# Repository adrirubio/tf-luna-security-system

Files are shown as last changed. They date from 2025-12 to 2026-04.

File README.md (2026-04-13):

# TF-Luna Security System
**Full Design Process**: [Blueprint Project](https://blueprint.hackclub.com/projects/7234)

An evolution of my Arduino-based security system that uses a TF-Luna LiDAR sensor to detect when someone passes through a bedroom door, triggering the ESP32-CAM to capture a photo of the intruder.

The system is built around a Freenove ESP32-S3-WROOM-1, which communicates with the TF-Luna over I2C to establish a baseline distance and detect motion. When an intruder is detected, the onboard camera captures an image and sends it to Home Assistant via Wi-Fi. A green LED indicates power status while a red LED flashes to signal an intruder alert. The entire system runs off a power bank and is housed in a custom 3D-printed case mounted with a custom carrier PCB, making it a compact, self-contained DIY security setup with future plans for AI-based person identification.

## Features

- **Intruder Detection:** Real-time motion detection using a TF-Luna LiDAR sensor with a focused 2-degree beam
- **Automatic Photo Capture:** ESP32-CAM captures an image when an intruder is detected passing through the door
- **Home Assistant Integration:** Sends captured images and alerts directly to Home Assistant over Wi-Fi
- **LED Indicators:** Green LED for power status, red LED flashes on intruder detection
- **I2C Communication:** Reliable sensor communication at 100Hz with the TF-Luna
- **Custom PCB:** Single carrier board designed in KiCad and manufactured by JLCPCB
- **Custom 3D Printed Case:** Designed in FreeCAD with mounting pillars and cutouts for all components
- **Power Bank Powered:** Runs off a standard power bank for easy and flexible placement
- **Autonomous Operation:** Runs continuously without manual interaction
- **Future AI Integration:** Planned AI-based identification to recognize the homeowner

## Hardware/BOM

| Component | Qty | Type |
|---|-----|---|
| Freenove ESP32-S3-WROOM-1 | 1 | Controller |
| TF-Luna LiDAR Sensor | 1 | LiDAR Sensor |
| microSD Card (32GB) | 1 | Storage |
| Custom Carrier PCB | 1 | PCB |
| Custom 3D Printed Case | 1 | Enclosure |
| Power Bank | 1 | Power |
| USB-A to USB-C Cable | 1 | Cable |
| Mounting Hardware (Assorted Screws) | 1 | Hardware |

## CAD Screenshots

| CAD Assembly (Front View)| CAD Assembly (Top View) |
|---|---|
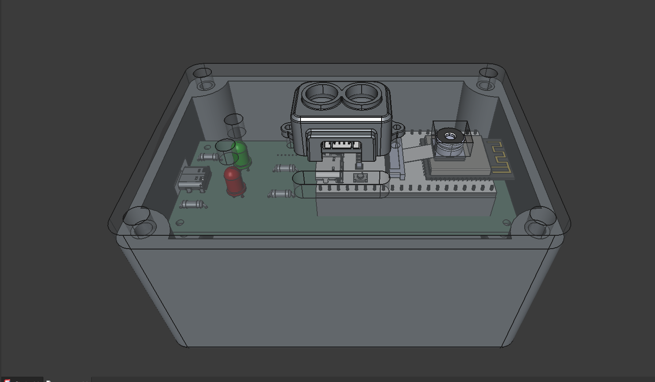
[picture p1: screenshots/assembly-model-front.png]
Assembly Model Front
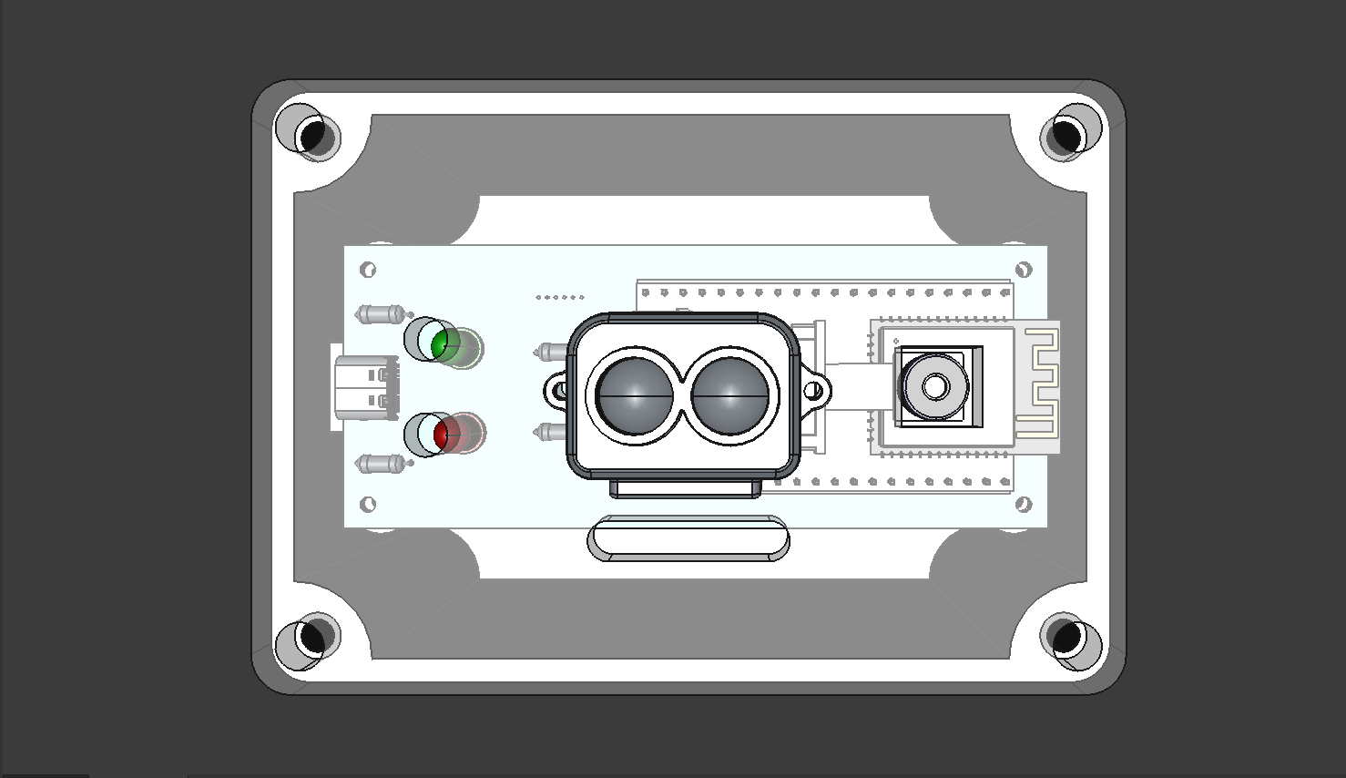
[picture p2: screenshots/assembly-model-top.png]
Assembly Model Top
|  |  |

| 3D Case (Front View) | 3D Case (Side View) |
|---|---|
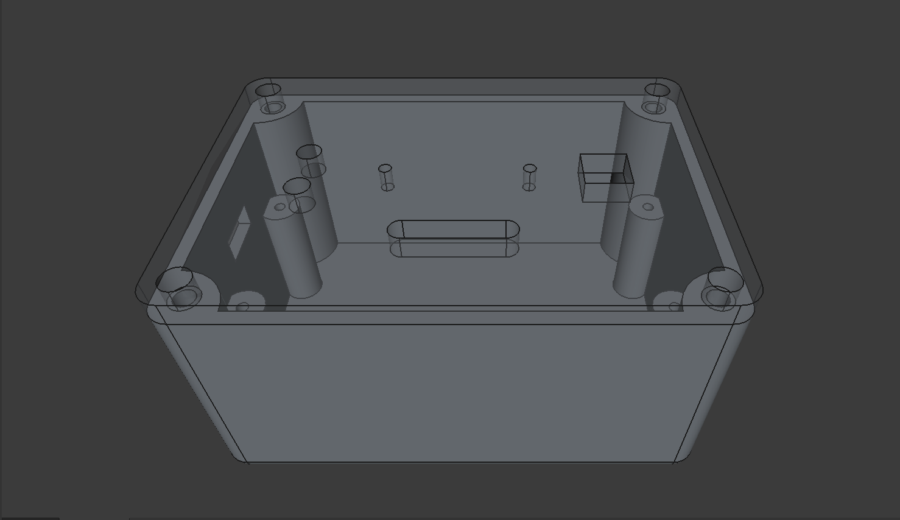
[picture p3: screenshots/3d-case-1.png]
3D Case Front
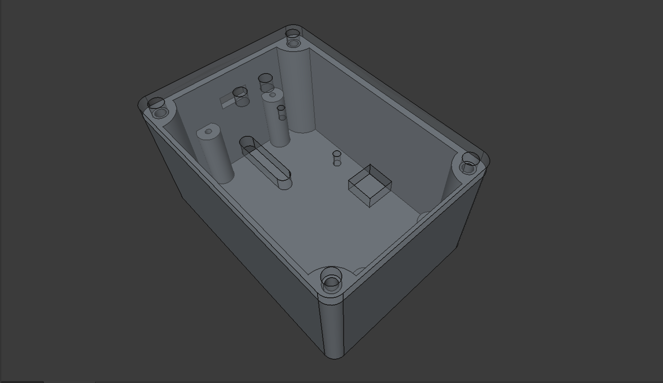
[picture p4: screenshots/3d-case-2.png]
3D Case Side
|  |  |

## PCB Screenshots

| PCB Layout |
|-------------------------------|
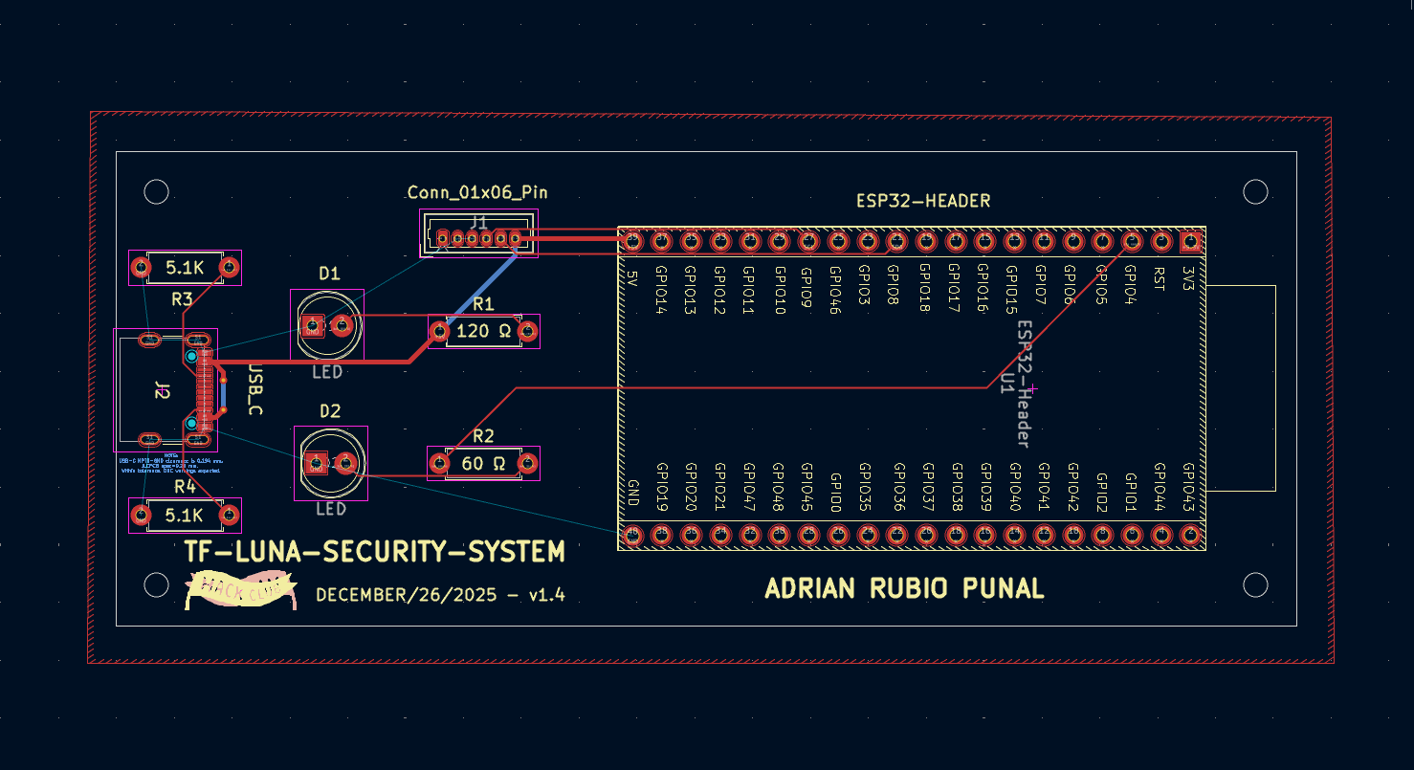
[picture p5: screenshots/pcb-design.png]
PCB Layout
|  |

| PCB 3D View (Front) | PCB 3D View (Back) |
|---|---|
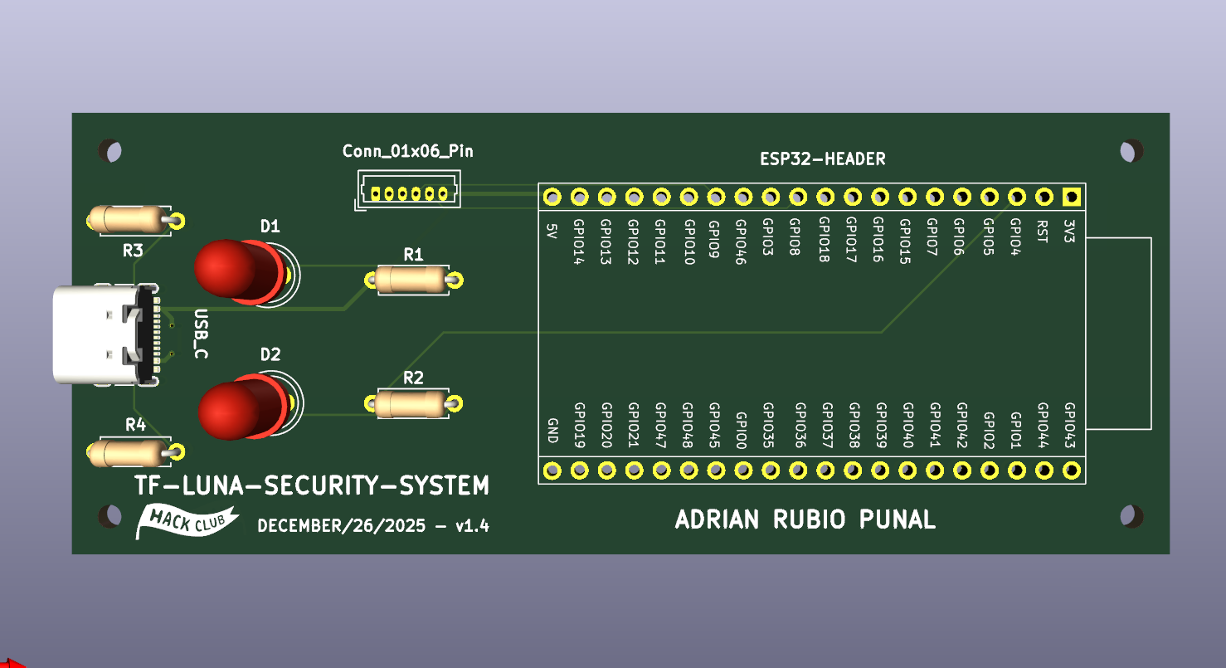
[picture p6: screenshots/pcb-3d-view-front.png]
PCB 3D View (Front)
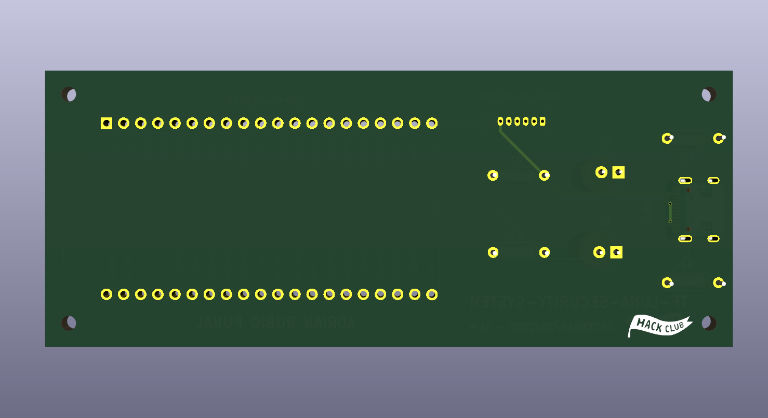
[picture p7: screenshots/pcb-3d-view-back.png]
PCB 3D View (Back)
|  |  |

## Usage
Mount the system above your bedroom door using the 3D-printed case. The TF-Luna LiDAR sensor establishes a baseline distance to the floor and continuously monitors for changes. When someone passes through the doorway, the sensor detects the distance change and triggers the ESP32-CAM to capture a photo. The image is then sent to Home Assistant over Wi-Fi, and the red LED flashes to indicate an intruder was detected. The green LED stays on to confirm the system is powered and running.

## TF-Luna Security System In Action

| Complete Assembly (Side View)|
|------------------------------|
| Complete Assembly Side |

| Complete Assembly (PCB and Case View) | Complete Assembly (Back View) |
|---|---|
| Complete Assembly PCB and Case | Complete Assembly Back |

### Security System Demo
<a href="https://github.com/adrirubio/tf-luna-security-system/raw/main/demo/video/security-system-demo.mp4">Click here to download the security system demo video (MP4)</a>

### YouTube Demo
[Watch the demo on YouTube](https://youtu.be/43d7Ib5dUhA)

## License

MIT License

---

> GitHub [@adrirubio](https://github.com/adrirubio) &nbsp;&middot;&nbsp;

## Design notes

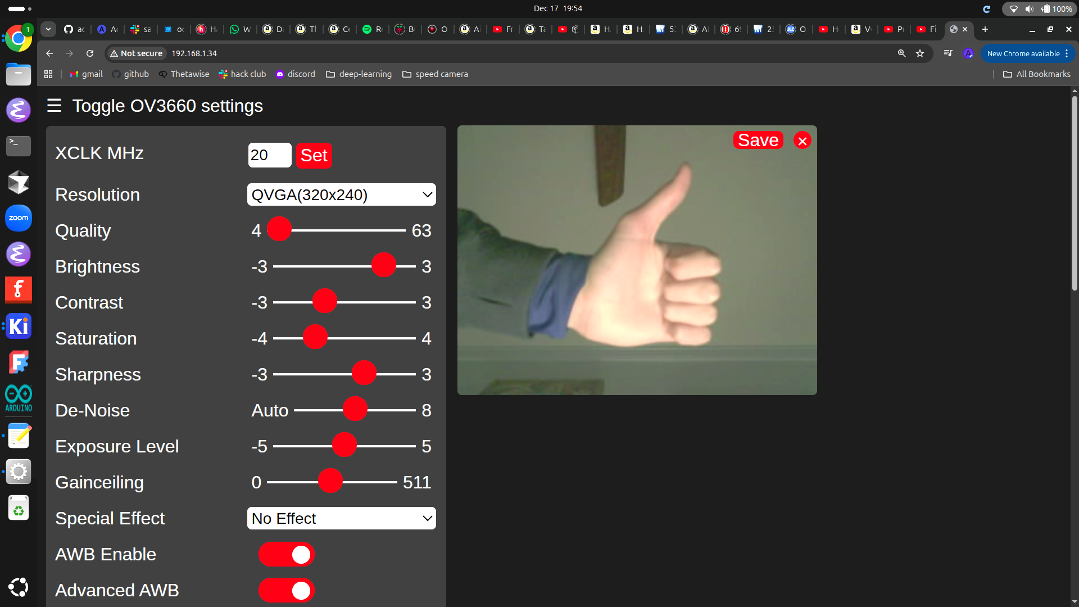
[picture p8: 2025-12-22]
demo/ESP32-S3-WebServer-picture/webserver-thumbs-up.png

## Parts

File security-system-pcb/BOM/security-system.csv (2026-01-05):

Comment | Designator | Footprint | LCSC Part Number
USB Type-C Receptacle, USB 2.0, Right-Angle, Top-Mount, SMT, TH Shell Stakes, 5A 48V | J2 | USB_C_Receptacle_GCT_USB4105-xx-A_16P_TopMnt_Horizontal | C3020560

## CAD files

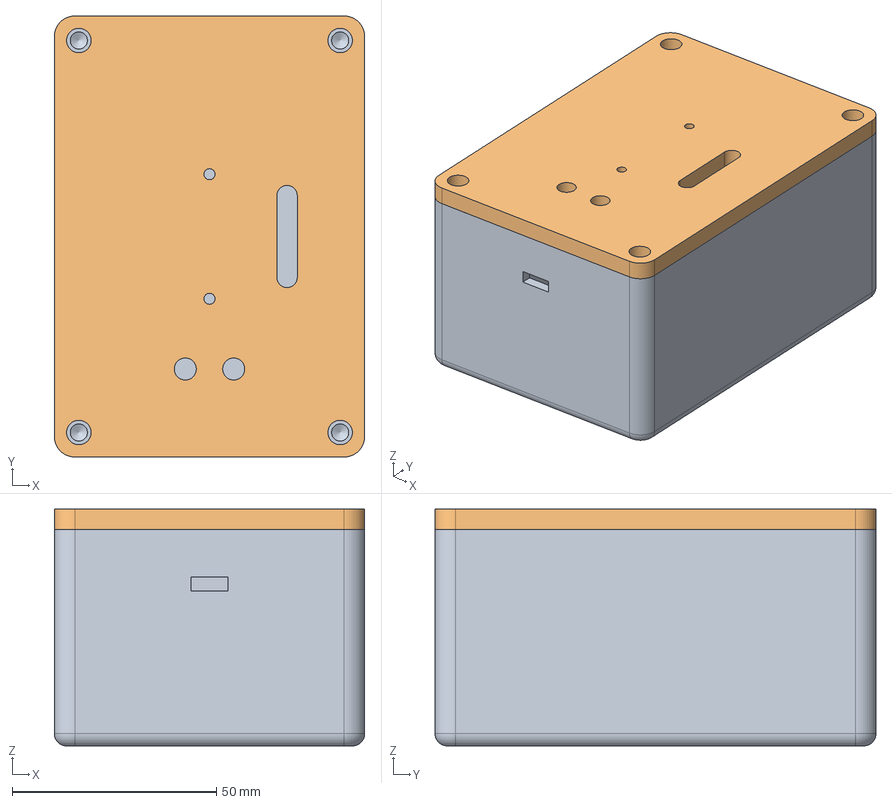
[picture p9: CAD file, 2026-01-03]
security-system-case/Case.FCStd
76.0 x 108.0 x 58.0 mm
case-base
case-cover

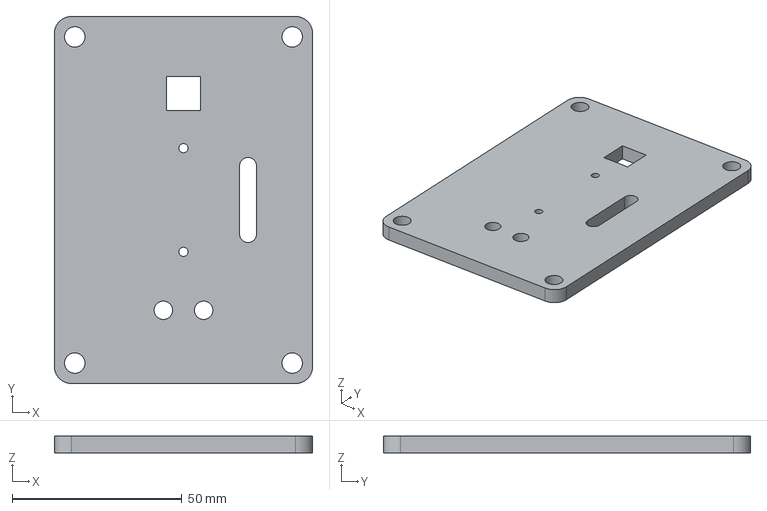
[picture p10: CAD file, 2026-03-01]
security-system-case/STEP-files/case-cover.step
76.0 x 108.0 x 5.00 mm

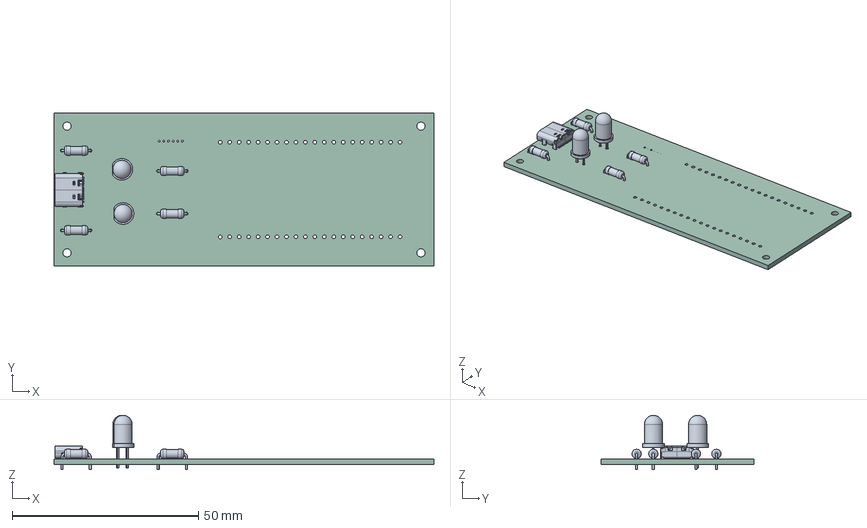
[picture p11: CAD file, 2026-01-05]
security-system-pcb/security-system-pcb/security-system.step
102.0 x 41.0 x 14.6 mm
LED_D5.0mm x 2
R_Axial_DIN0207_L6.3mm_D2.5mm_P7.62mm_Horizontal x 4
USB_C_Receptacle_GCT_USB4105-xx-A_16P_TopMnt_Horizontal
security-system_PCB

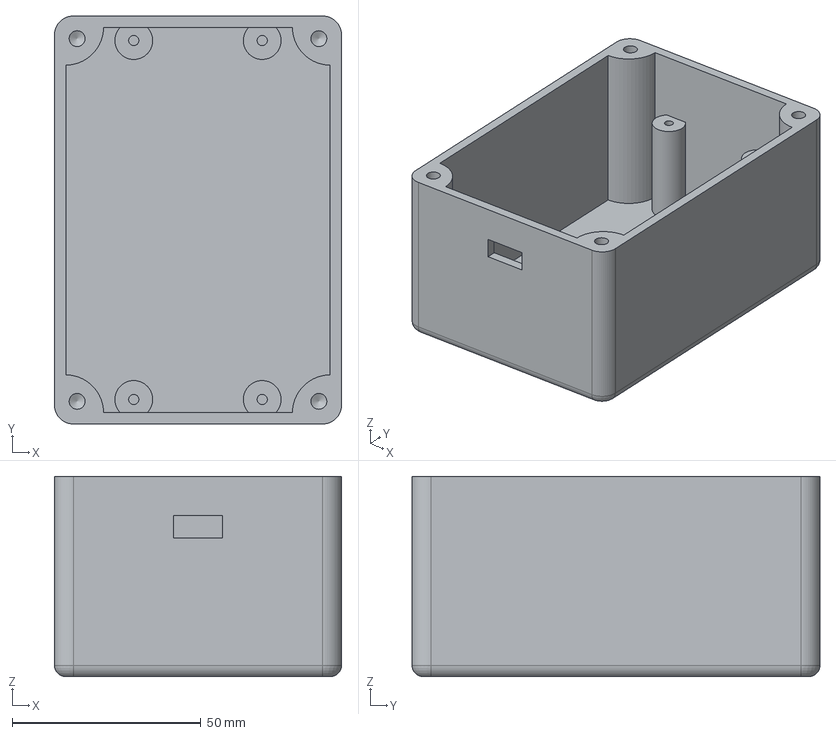
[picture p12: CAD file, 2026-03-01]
security-system-case/STEP-files/case-base.step
76.0 x 108.0 x 53.0 mm

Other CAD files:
security-system-case/STL-files/enclosure-cover.stl
security-system-case/STL-files/enclosure-base.stl

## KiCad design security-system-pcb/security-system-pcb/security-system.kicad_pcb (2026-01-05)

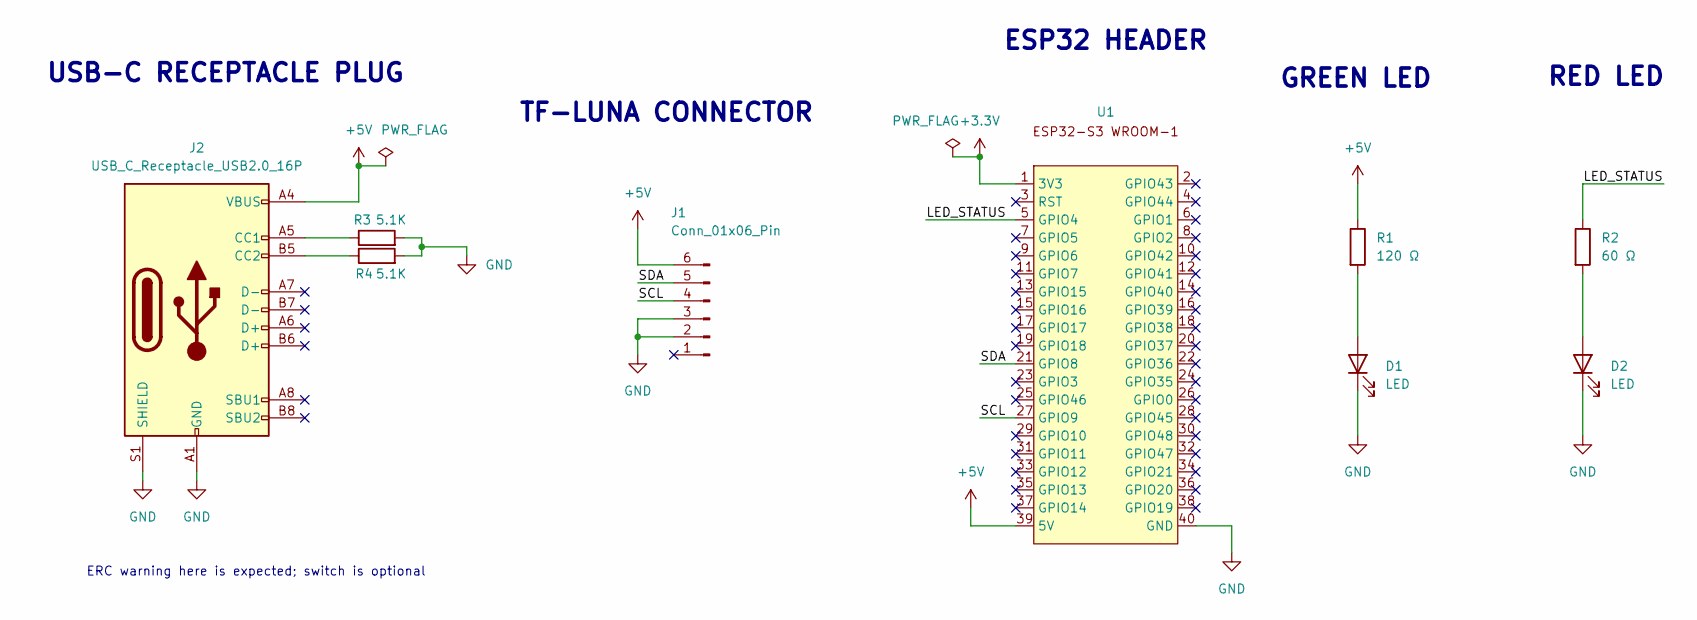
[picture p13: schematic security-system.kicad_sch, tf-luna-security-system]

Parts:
D1, D2: LED; LED_D5.0mm
J1: Conn_01x06_Pin; Molex_PicoBlade_53047-0610_1x06_P1.25mm_Vertical
J2: USB_C_Receptacle_USB2.0_16P; USB_C_Receptacle_GCT_USB4105-xx-A_16P_TopMnt_Horizontal
R1: 120 Ω; R_Axial_DIN0207_L6.3mm_D2.5mm_P7.62mm_Horizontal
R2: 60 Ω; R_Axial_DIN0207_L6.3mm_D2.5mm_P7.62mm_Horizontal
R3, R4: 5.1K; R_Axial_DIN0207_L6.3mm_D2.5mm_P7.62mm_Horizontal
U1: ESP32-Header; esp32-header

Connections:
+3.3V: U1.1 (3V3)
+5V: J1.6, J2.A4 (VBUS), J2.A9 (VBUS), J2.B4 (VBUS), J2.B9 (VBUS), R1.1, U1.39 (5V)
/LED_STATUS: R2.1, U1.5 (GPIO4)
/SCL: J1.4, U1.27 (GPIO9)
/SDA: J1.5, U1.21 (GPIO8)
GND: D1.1 (K), D2.1 (K), J1.2, J1.3, J2.A1 (GND), J2.A12 (GND), J2.B1 (GND), J2.B12 (GND), J2.S1 (SHIELD), R3.2, R4.2, U1.40 (GND)
unnamed: D1.2 (A), R1.2
unnamed: D2.2 (A), R2.2
unnamed: J2.A5 (CC1), R3.1
unnamed: J2.B5 (CC2), R4.1

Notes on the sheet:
TF-LUNA CONNECTOR
RED LED
USB-C RECEPTACLE PLUG
ERC warning here is expected; switch is optional
GREEN LED
ESP32 HEADER

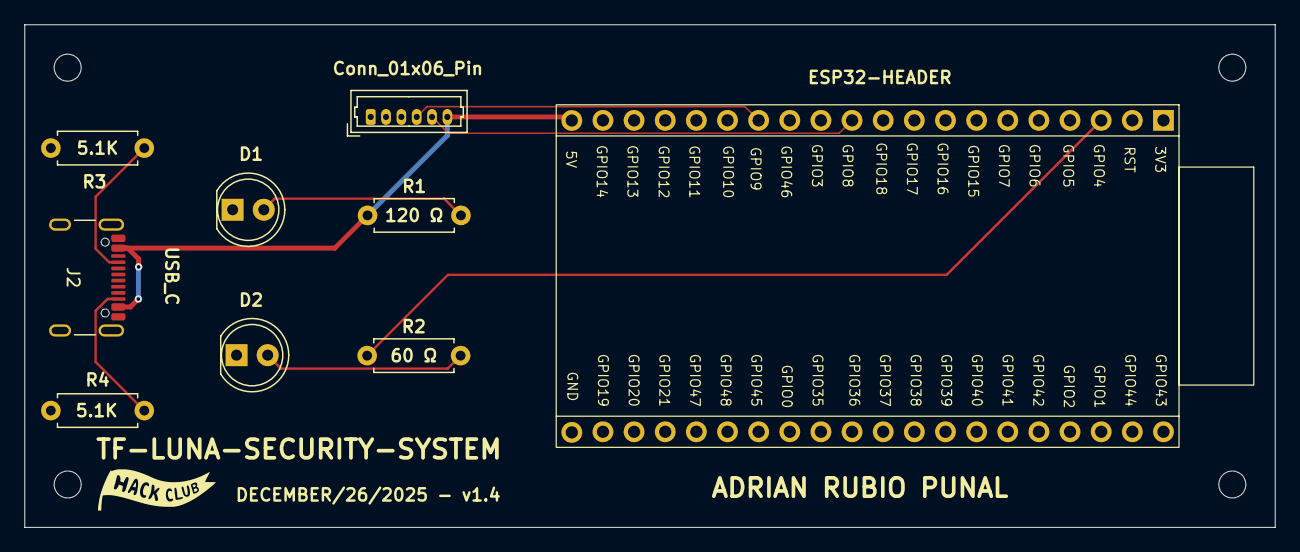
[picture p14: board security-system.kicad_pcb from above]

Board: 2 copper layers, 102.0 x 41.0 mm, 9 parts (0 on the bottom side), 9 nets.

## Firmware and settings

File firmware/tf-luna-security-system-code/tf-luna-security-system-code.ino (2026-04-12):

// ============================================================================
//  Security System — TF-Luna + ESP32-S3 Camera
// ----------------------------------------------------------------------------
//  IMPORTANT: In Arduino IDE select a partition scheme with at least ~2 MB of
//  LittleFS/SPIFFS space (e.g. "8M with spiffs (3MB APP/1.5MB SPIFFS)" or
//  larger). LittleFS reuses the SPIFFS partition. Without enough space the
//  circular photo buffer will drop captures.
// ============================================================================

#include <Wire.h>
#include <WiFi.h>
#include <WebServer.h>
#include <ESPmDNS.h>
#include <TFLI2C.h>
#include <LittleFS.h>
#include <time.h>
#include "esp_camera.h"

// mDNS hostname: http://security-system.local/
#define MDNS_HOSTNAME "security-system"

#include "board_config.h"

// ---- Wi-Fi Station settings ----
const char *WIFI_SSID = "MOVISTAR-WIFI6-B410";
const char *WIFI_PASS = "LE2xPxeBy7jPvEKYT6Qw";

// ---- TF-Luna I2C ----
TFLI2C tflI2C;
uint8_t tflunaAddr = 0x10;

// ---- Detection settings ----
#define WARMUP_MS           5000     // wait 5s before touching the sensor
#define BASELINE_MS         10000    // sample baseline for 10s
#define BASELINE_INTERVAL   100      // ms between baseline samples
#define TRIGGER_THRESHOLD   20       // cm — clearly something in the way
#define COOLDOWN_MS         250      // ms lockout after a capture (fast burst)
#define POLL_INTERVAL_MS    100      // monitoring sample interval
#define MAX_VALID_DIST      800      // TF-Luna max range cm

// ---- Sensor health ----
#define BAD_READ_LIMIT      8        // consecutive bad reads → degraded mode
#define RESET_RECOVER_MS    1500     // time to allow after a quick reset

// ---- Photo storage ----
#define MAX_PHOTOS          100
#define META_PATH           "/meta.bin"

// ---- System state ----
enum SystemState { STATE_WARMUP, STATE_CALIBRATING, STATE_MONITORING, STATE_TRIGGERED, STATE_COOLDOWN };
volatile SystemState systemState = STATE_WARMUP;

int  baselineDistance  = 0;
int  lastDistance      = -1;
int  lastBreakDistance = 0;
unsigned long lastBreakEpoch = 0;

unsigned long stateStart    = 0;
unsigned long cooldownStart = 0;
unsigned long bootMillis    = 0;

long calibSum   = 0;
int  calibCount = 0;

// ---- Sensor health tracking ----
int  badReadStreak   = 0;
bool degraded        = false;
int  totalQuickResets = 0;

// ---- Persistent metadata (saved to LittleFS) ----
struct __attribute__((packed)) Meta {
  uint32_t magic;                  // 0x5345434B "SECK"
  uint32_t nextIndex;              // next slot to write (0..MAX_PHOTOS-1)
  uint32_t totalCaptures;          // lifetime counter
  uint32_t epoch[MAX_PHOTOS];      // unix epoch for each slot (0 if empty)
  int16_t  distance[MAX_PHOTOS];   // distance at trigger
  int16_t  baseline[MAX_PHOTOS];   // baseline at trigger
};
Meta meta;

// ---- Web server ----
WebServer server(80);

// ======================= I2C =======================

void startI2C() {
  pinMode(8, INPUT_PULLUP);
  pinMode(9, INPUT_PULLUP);
  Wire.begin(8, 9);
  Wire.setClock(100000);
}

void stopI2C() {
  Wire.end();
}

// ======================= TF-Luna =======================

// Aggressive boot-time recovery: scan the bus, hard-reset whatever
// looks like a TF-Luna at any address, and wait for it to come back
// at the default 0x10. Survives a sensor whose EEPROM got corrupted
// into a non-default I2C address.
void tflunaForceFactoryReset() {
  Serial.println("TF-Luna: forcing factory reset...");

  for (int attempt = 1; attempt <= 3; attempt++) {
    Serial.printf("  Attempt %d/3\n", attempt);

    // 1. Scan bus
    uint8_t found[8];
    int nFound = 0;
    for (uint8_t a = 0x08; a <= 0x77 && nFound < 8; a++) {
      Wire.beginTransmission(a);
      if (Wire.endTransmission() == 0) {
        Serial.printf("    bus device @ 0x%02X\n", a);
        found[nFound++] = a;
      }
    }
    if (nFound == 0) {
      Serial.println("    no I2C devices on bus — check wiring/power");
      delay(500);
      continue;
    }

    // 2. Hard-reset every responding address (TF-Luna ignores reset
    //    sent to wrong address — safe to spray)
    for (int i = 0; i < nFound; i++) {
      Serial.printf("    Hard_Reset(0x%02X)\n", found[i]);
      tflI2C.Hard_Reset(found[i]);
      delay(200);
    }

    // 3. Wait for sensor to reboot
    Serial.println("    waiting 4s for reboot...");
    delay(4000);

    // 4. Bounce the bus so the controller forgets any stuck state
    stopI2C();
    delay(100);
    startI2C();
    delay(300);

    // 5. Verify default address is alive
    Wire.beginTransmission(tflunaAddr);
    if (Wire.endTransmission() == 0) {
      Serial.printf("    TF-Luna present @ 0x%02X — restoring defaults\n", tflunaAddr);
      tflI2C.Soft_Reset(tflunaAddr);    delay(800);
      tflI2C.Set_Enable(tflunaAddr);    delay(50);
      tflI2C.Set_Cont_Mode(tflunaAddr); delay(50);
      uint16_t fps = 10;               // 10Hz — match our poll rate, save power
      tflI2C.Set_Frame_Rate(fps, tflunaAddr); delay(50);
      // NOT calling Save_Settings — protect EEPROM from wear
      Serial.println("TF-Luna: factory reset complete");
      return;
    }
    Serial.println("    sensor not at 0x10 yet, retrying...");
  }
  Serial.println("TF-Luna: factory reset gave up — continuing anyway");
}

// Quick reset: bounce I2C bus + soft-reset sensor. Same effect as
// unplug/replug but without touching the cable. Takes ~1.5s.
void tflunaQuickReset() {
  Serial.println("TF-Luna: quick reset (I2C bounce + soft reset)...");
  totalQuickResets++;
  stopI2C();
  delay(100);
  startI2C();
  delay(200);
  tflI2C.Soft_Reset(tflunaAddr);
  delay(800);
  tflI2C.Set_Enable(tflunaAddr);
  delay(50);
  tflI2C.Set_Cont_Mode(tflunaAddr);
  delay(50);
  uint16_t fps = 10;                  // 10Hz — match poll rate, save power
  tflI2C.Set_Frame_Rate(fps, tflunaAddr);
  delay(50);
  badReadStreak = 0;
  Serial.println("TF-Luna: quick reset done");
}

int tflunaReadDistance() {
  int16_t dist = 0, flux = 0, temp = 0;
  bool ok = tflI2C.getData(dist, flux, temp, tflunaAddr);

  if (ok && dist > 0 && dist <= MAX_VALID_DIST && flux > 20) {
    // Good read — healthy signal
    if (badReadStreak > 0) badReadStreak--;
    if (badReadStreak == 0 && degraded) {
      degraded = false;
      Serial.println("Sensor: readings recovered");
    }
    return dist;
  }

  // Log what the sensor actually returned so we can diagnose
  if (ok) {
    Serial.printf("Sensor: suspect read dist=%d flux=%d temp=%d\n",
                  dist, flux, temp);
  }

  badReadStreak++;
  if (badReadStreak >= BAD_READ_LIMIT && !degraded) {
    degraded = true;
    Serial.printf("Sensor: DEGRADED (%d consecutive bad reads)\n", badReadStreak);
    tflunaQuickReset();
  }
  return -1;
}

// ======================= Camera =========================

static bool startCamera() {
  camera_config_t config;
  config.ledc_channel = LEDC_CHANNEL_0;
  config.ledc_timer   = LEDC_TIMER_0;

  config.pin_d0 = Y2_GPIO_NUM;
  config.pin_d1 = Y3_GPIO_NUM;
  config.pin_d2 = Y4_GPIO_NUM;
  config.pin_d3 = Y5_GPIO_NUM;
  config.pin_d4 = Y6_GPIO_NUM;
  config.pin_d5 = Y7_GPIO_NUM;
  config.pin_d6 = Y8_GPIO_NUM;
  config.pin_d7 = Y9_GPIO_NUM;

  config.pin_xclk  = XCLK_GPIO_NUM;
  config.pin_pclk  = PCLK_GPIO_NUM;
  config.pin_vsync = VSYNC_GPIO_NUM;
  config.pin_href  = HREF_GPIO_NUM;

  config.pin_sccb_sda = SIOD_GPIO_NUM;
  config.pin_sccb_scl = SIOC_GPIO_NUM;

  config.pin_pwdn  = PWDN_GPIO_NUM;
  config.pin_reset = RESET_GPIO_NUM;

  config.xclk_freq_hz = 10000000;
  config.pixel_format = PIXFORMAT_JPEG;
  config.frame_size   = FRAMESIZE_VGA;
  config.jpeg_quality = 18;          // higher number = smaller file
  config.fb_count     = 1;
  config.grab_mode    = CAMERA_GRAB_WHEN_EMPTY;

  if (psramFound()) {
    config.fb_location = CAMERA_FB_IN_PSRAM;
  } else {
    config.fb_location = CAMERA_FB_IN_DRAM;
  }

  esp_err_t err = esp_camera_init(&config);
  if (err != ESP_OK) {
    Serial.printf("Camera init failed: 0x%x\n", err);
    return false;
  }
  return true;
}

static void stopCamera() {
  esp_camera_deinit();
}

// ======================= Storage ========================

String photoPath(uint32_t slot) {
  char buf[20];
  snprintf(buf, sizeof(buf), "/img_%03lu.jpg", (unsigned long)slot);
  return String(buf);
}

void saveMeta() {
  File f = LittleFS.open(META_PATH, "w");
  if (!f) {
    Serial.println("saveMeta: open failed");
    return;
  }
  f.write((const uint8_t *)&meta, sizeof(meta));
  f.close();
}

void loadMeta() {
  memset(&meta, 0, sizeof(meta));
  meta.magic = 0x5345434B;
  if (!LittleFS.exists(META_PATH)) {
    Serial.println("No meta file — starting fresh");
    return;
  }
  File f = LittleFS.open(META_PATH, "r");
  if (!f) return;
  if (f.size() != sizeof(Meta)) {
    Serial.println("meta.bin size mismatch — resetting");
    f.close();
    memset(&meta, 0, sizeof(meta));
    meta.magic = 0x5345434B;
    return;
  }
  f.read((uint8_t *)&meta, sizeof(meta));
  f.close();
  if (meta.magic != 0x5345434B) {
    Serial.println("meta.bin magic bad — resetting");
    memset(&meta, 0, sizeof(meta));
    meta.magic = 0x5345434B;
    return;
  }
  Serial.printf("Loaded meta: nextIndex=%u totalCaptures=%u\n",
                meta.nextIndex, meta.totalCaptures);
}

uint32_t storedPhotoCount() {
  return meta.totalCaptures < MAX_PHOTOS ? meta.totalCaptures : MAX_PHOTOS;
}

// Slot of newest photo (nth = 0 means newest)
int32_t nthNewestSlot(uint32_t n) {
  uint32_t count = storedPhotoCount();
  if (n >= count) return -1;
  // nextIndex points to where the NEXT photo will be written
  int32_t slot = ((int32_t)meta.nextIndex - 1 - (int32_t)n);
  slot %= MAX_PHOTOS;
  if (slot < 0) slot += MAX_PHOTOS;
  return slot;
}

// ======================= Capture ========================

bool capturePhoto(int distanceAtTrigger) {
  stopI2C();
  delay(10);

  if (!startCamera()) {
    Serial.println("Camera init failed");
    startI2C();
    return false;
  }

  camera_fb_t *fb = esp_camera_fb_get();
  if (!fb) {
    Serial.println("Capture failed");
    stopCamera();
    startI2C();
    return false;
  }

  uint32_t slot = meta.nextIndex % MAX_PHOTOS;
  String path = photoPath(slot);
  if (LittleFS.exists(path)) LittleFS.remove(path);

  bool ok = false;
  File f = LittleFS.open(path, "w");
  if (f) {
    size_t wrote = f.write(fb->buf, fb->len);
    f.close();
    ok = (wrote == fb->len);
    if (!ok) {
      Serial.println("Photo write incomplete");
      LittleFS.remove(path);
    }
  } else {
    Serial.println("Photo open for write failed");
  }

  Serial.printf("Photo %s (%u bytes) %s\n", path.c_str(),
                (unsigned)fb->len, ok ? "OK" : "FAIL");

  esp_camera_fb_return(fb);
  stopCamera();
  delay(10);
  startI2C();

  if (ok) {
    time_t now = time(nullptr);
    meta.epoch[slot]    = (now > 1700000000) ? (uint32_t)now : 0;
    meta.distance[slot] = (int16_t)distanceAtTrigger;
    meta.baseline[slot] = (int16_t)baselineDistance;
    meta.nextIndex      = (meta.nextIndex + 1) % MAX_PHOTOS;
    meta.totalCaptures++;
    saveMeta();
    lastBreakDistance = distanceAtTrigger;
    lastBreakEpoch    = (now > 1700000000) ? (uint32_t)now : 0;
  }
  return ok;
}

// ======================= Helpers =========================

String formatUptime(unsigned long ms) {
  unsigned long secs = ms / 1000;
  unsigned long mins = secs / 60;
  unsigned long hrs  = mins / 60;
  char buf[16];
  snprintf(buf, sizeof(buf), "%02lu:%02lu:%02lu",
           hrs, mins % 60, secs % 60);
  return String(buf);
}

String formatEpoch(uint32_t epoch) {
  if (epoch < 1700000000) return String("—");
  time_t t = epoch;
  struct tm tmv;
  localtime_r(&t, &tmv);
  char buf[24];
  snprintf(buf, sizeof(buf), "%04d-%02d-%02d %02d:%02d:%02d",
           tmv.tm_year + 1900, tmv.tm_mon + 1, tmv.tm_mday,
           tmv.tm_hour, tmv.tm_min, tmv.tm_sec);
  return String(buf);
}

const char *stateName(SystemState s) {
  switch (s) {
    case STATE_WARMUP:      return "WARMUP";
    case STATE_CALIBRATING: return "CALIBRATING";
    case STATE_MONITORING:  return "MONITORING";
    case STATE_TRIGGERED:   return "TRIGGERED";
    case STATE_COOLDOWN:    return "COOLDOWN";
  }
  return "UNKNOWN";
}

// ======================= Web: shared CSS ================

const char PAGE_CSS[] PROGMEM = R"CSS(
:root{
  --bg:#050505;--panel:#0b0b0b;--border:#1a1a1a;--border-hi:#262626;
  --fg:#c8c8c8;--dim:#555;--accent:#00ff66;--accent-dim:#00aa44;
  --warn:#ff3344;--info:#00d0ff;--amber:#ffb000;
}
*{box-sizing:border-box;margin:0;padding:0}
html,body{background:var(--bg);color:var(--fg);
  font-family:'JetBrains Mono','Fira Code',Menlo,Consolas,monospace;
  min-height:100vh}
body{padding:24px;max-width:1400px;margin:0 auto}
a{color:var(--accent);text-decoration:none}
header{display:flex;align-items:center;justify-content:space-between;
  padding-bottom:16px;border-bottom:1px solid var(--border);margin-bottom:24px}
header h1{font-size:1.3rem;letter-spacing:.2em;color:var(--accent);font-weight:400}
header h1::before{content:'> ';color:var(--accent-dim)}
.state{font-size:.7rem;letter-spacing:.2em;padding:5px 14px;
  border:1px solid var(--border-hi);text-transform:uppercase;color:var(--accent)}
.state.warmup,.state.calibrating{color:var(--info);border-color:var(--info)}
.state.monitoring{color:var(--accent);border-color:var(--accent-dim)}
.state.triggered{color:var(--warn);border-color:var(--warn)}
.state.cooldown{color:var(--amber);border-color:var(--amber)}
main{display:grid;grid-template-columns:minmax(280px,1fr) 2fr;gap:20px}
@media(max-width:760px){main{grid-template-columns:1fr}}
.panel{background:var(--panel);border:1px solid var(--border);padding:18px}
.panel h2{font-size:.65rem;letter-spacing:.25em;color:var(--accent-dim);
  text-transform:uppercase;margin-bottom:14px;font-weight:400}
.panel h2::before{content:'// '}
.row{display:flex;justify-content:space-between;align-items:baseline;
  padding:7px 0;border-bottom:1px dashed #141414;font-size:.82rem}
.row:last-child{border:0}
.label{color:var(--dim)}
.val{color:var(--accent)}
.val.warn{color:var(--warn)}
.val.dim{color:var(--dim)}
.image-wrap{display:flex;align-items:center;justify-content:center;
  min-height:320px;background:#000;border:1px solid var(--border)}
.image-wrap img{width:100%;height:auto;display:block;filter:contrast(1.05) saturate(.95)}
.image-empty{color:var(--dim);font-size:.8rem;letter-spacing:.15em;padding:60px 0}
.caption{font-size:.7rem;color:var(--dim);padding:10px 2px 0;
  display:flex;justify-content:space-between}
.caption .val{color:var(--accent-dim)}
.actions{margin-top:24px;display:flex;gap:12px;flex-wrap:wrap}
.btn{display:inline-block;padding:10px 20px;background:transparent;
  color:var(--accent);border:1px solid var(--accent-dim);font-family:inherit;
  font-size:.75rem;letter-spacing:.18em;text-transform:uppercase;cursor:pointer;
  transition:.15s}
.btn:hover{background:var(--accent);color:var(--bg)}
.btn.ghost{color:var(--dim);border-color:var(--border-hi)}
.btn.ghost:hover{background:var(--border-hi);color:var(--fg)}
footer{margin-top:32px;padding-top:12px;border-top:1px solid var(--border);
  font-size:.65rem;color:var(--dim);letter-spacing:.15em;text-align:center}
footer::before{content:'[ '}footer::after{content:' ]'}
.grid{display:grid;grid-template-columns:repeat(auto-fill,minmax(170px,1fr));gap:8px}
.tile{position:relative;border:1px solid var(--border);background:#000;
  aspect-ratio:4/3;overflow:hidden}
.tile img{width:100%;height:100%;object-fit:cover;display:block}
.tile .badge{position:absolute;top:4px;left:4px;font-size:.6rem;color:var(--accent);
  background:rgba(0,0,0,.75);padding:2px 6px;letter-spacing:.1em}
.tile .meta{position:absolute;bottom:0;left:0;right:0;font-size:.6rem;
  color:var(--dim);background:linear-gradient(transparent,rgba(0,0,0,.85));
  padding:14px 6px 5px}
.tile:hover{border-color:var(--accent-dim)}
.empty-gallery{color:var(--dim);padding:40px;text-align:center;font-size:.8rem;
  letter-spacing:.15em;border:1px dashed var(--border-hi)}
.degraded-banner{display:none;background:#0a0800;border:1px solid #332200;
  padding:12px 16px;margin-bottom:20px;font-size:.72rem;letter-spacing:.12em;
  color:var(--amber);position:relative;overflow:hidden}
.degraded-banner.active{display:block}
.degraded-banner::before{content:'WARNING // ';color:#664400}
.degraded-banner .glitch{animation:flk .15s infinite alternate}
@keyframes flk{0%{opacity:1}100%{opacity:.4}}
)CSS";

// ======================= Web: root =====================
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
void loop() {
  server.handleClient();

  unsigned long now = millis();

  switch (systemState) {

    case STATE_WARMUP: {
      if (now - stateStart >= WARMUP_MS) {
        systemState = STATE_CALIBRATING;
        stateStart  = now;
        calibSum    = 0;
        calibCount  = 0;
        Serial.println("Calibrating baseline (10s)...");
      }
      break;
    }

    case STATE_CALIBRATING: {
      static unsigned long lastSample = 0;
      if (now - lastSample >= BASELINE_INTERVAL) {
        lastSample = now;
        int d = tflunaReadDistance();
        if (d > 0) {
          calibSum += d;
          calibCount++;
        }
      }
      if (now - stateStart >= BASELINE_MS) {
        if (calibCount > 0) {
          baselineDistance = calibSum / calibCount;
          Serial.printf("Baseline = %d cm (%d samples)\n",
                        baselineDistance, calibCount);
        } else {
          baselineDistance = 0;
          Serial.println("Baseline: no valid samples");
        }
        systemState = STATE_MONITORING;
        Serial.println("Armed - monitoring");
      }
      break;
    }

    case STATE_MONITORING: {
      static unsigned long lastPoll = 0;
      if (now - lastPoll < POLL_INTERVAL_MS) break;
      lastPoll = now;

      int d = tflunaReadDistance();
      if (d <= 0) break;
      lastDistance = d;

      if (baselineDistance <= 0) break;  // no valid baseline → don't trigger

      int diff = abs(d - baselineDistance);
      if (diff >= TRIGGER_THRESHOLD) {
        Serial.printf("BREAK! dist=%d cm (baseline=%d, diff=%d)\n",
                      d, baselineDistance, diff);
        systemState = STATE_TRIGGERED;
        capturePhoto(d);
        systemState = STATE_MONITORING;
      }
      break;
    }

    case STATE_TRIGGERED:
      // transient — set only inside capturePhoto path
      break;
  }
}

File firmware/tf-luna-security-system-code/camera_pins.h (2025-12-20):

#if defined(CAMERA_MODEL_ESP32S3_EYE)
#define PWDN_GPIO_NUM  -1
#define RESET_GPIO_NUM -1
#define XCLK_GPIO_NUM  15
#define SIOD_GPIO_NUM  4
#define SIOC_GPIO_NUM  5

#define Y2_GPIO_NUM 11
#define Y3_GPIO_NUM 9
#define Y4_GPIO_NUM 8
#define Y5_GPIO_NUM 10
#define Y6_GPIO_NUM 12
#define Y7_GPIO_NUM 18
#define Y8_GPIO_NUM 17
#define Y9_GPIO_NUM 16

#define VSYNC_GPIO_NUM 6
#define HREF_GPIO_NUM  7
#define PCLK_GPIO_NUM  13

#else
#error "Camera model not selected"
#endif

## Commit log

2025-12-20 Add BOM file
2025-12-20 Push esp32 camera test code
2025-12-22 Add demo picture and pcb schematic
    [security-system.kicad_pcb, security-system.kicad_sch]
2025-12-26 Add PCB changes
    [security-system.kicad_pcb, security-system.kicad_sch]
2025-12-29 Add PCB changes and 3D case
    [Case.FCStd, Unnamed.FCStd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]
2025-12-30 Add updated gerbers
    [Case.FCStd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]
2026-01-01 Push PCB version 1.3
    [Case.FCStd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]
2026-01-01 Made small changes
    [security-system.kicad_pcb]
2026-01-02 Changes to the 3D case
    [Case.FCStd]
2026-01-03 Changes to the schematic and case
    [Case.FCStd]
2026-01-05 Push changes to case and gerbers v1.4
    [security-system-B_Mask.gbr, security-system-B_Paste.gbr, security-system-B_Silkscreen.gbr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]
2026-01-10 3D case changes
    [enclosure-base.stl, enclosure-cover.stl]
2026-03-01 Add STEP files
    [Unnamed.FCStd, case-base.step, case-cover.step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]
2026-04-07 Minor change to bom.csv
    [bom.csv]
